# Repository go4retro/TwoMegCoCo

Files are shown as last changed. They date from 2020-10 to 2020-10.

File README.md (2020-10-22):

# TwoMegCoCo - an SRAM-based 2048kB RAM Expansion for the TANDY Color Computer 3
A TTL logic, SRAM-based 2048kB (2MB) memory expansion for the Color Computer 3.  Upper bank registers are write-only, like the older Disto units. All parts are through hole for easy hobbyist assembly.

## Motivation

After acquiring a used Disto 2MB memory expansion, I wondered if a similar 1980's TTL-based solution could have been created using SRAM (ignoring the fact that 2MB of SRAM was extremely expensive at the time compared to DRAM), and I wanted to see if I could design a unit using only off-the-shelf TTL circuitry. (And, since, at time of writing this, the MMU extension PCB is still being debugged, the question is yet unanswered :-)).

Obviously, as with the HalfMegCoco project, there is little economic incentive in this project, as the contemporary commercial solutions offer more functionality at a cheaper price.  But, there's always some value in building a unit oneself, or at least understanding how the MMU process works by inspecting the actual TTL logic.

## Status

Currently, the SRAM board has been confirmed to work with various MMU extension solutions (Boysontech/Cloud9), but I am still designing and debugging the MMU board (would appreciate help, if there is interest).

## License
Copyright (C) 2020  RETRO Innovations

These files are free designs; you can redistribute them and/or modify
them under the terms of the Creative Commons Attribution-ShareAlike 
4.0 International License.

You should have received a copy of the license along with this
work. If not, see <http://creativecommons.org/licenses/by-sa/4.0/>.

These files are distributed in the hope that they will be useful,
but WITHOUT ANY WARRANTY; without even the implied warranty of
MERCHANTABILITY or FITNESS FOR A PARTICULAR PURPOSE.  See the
license for more details.

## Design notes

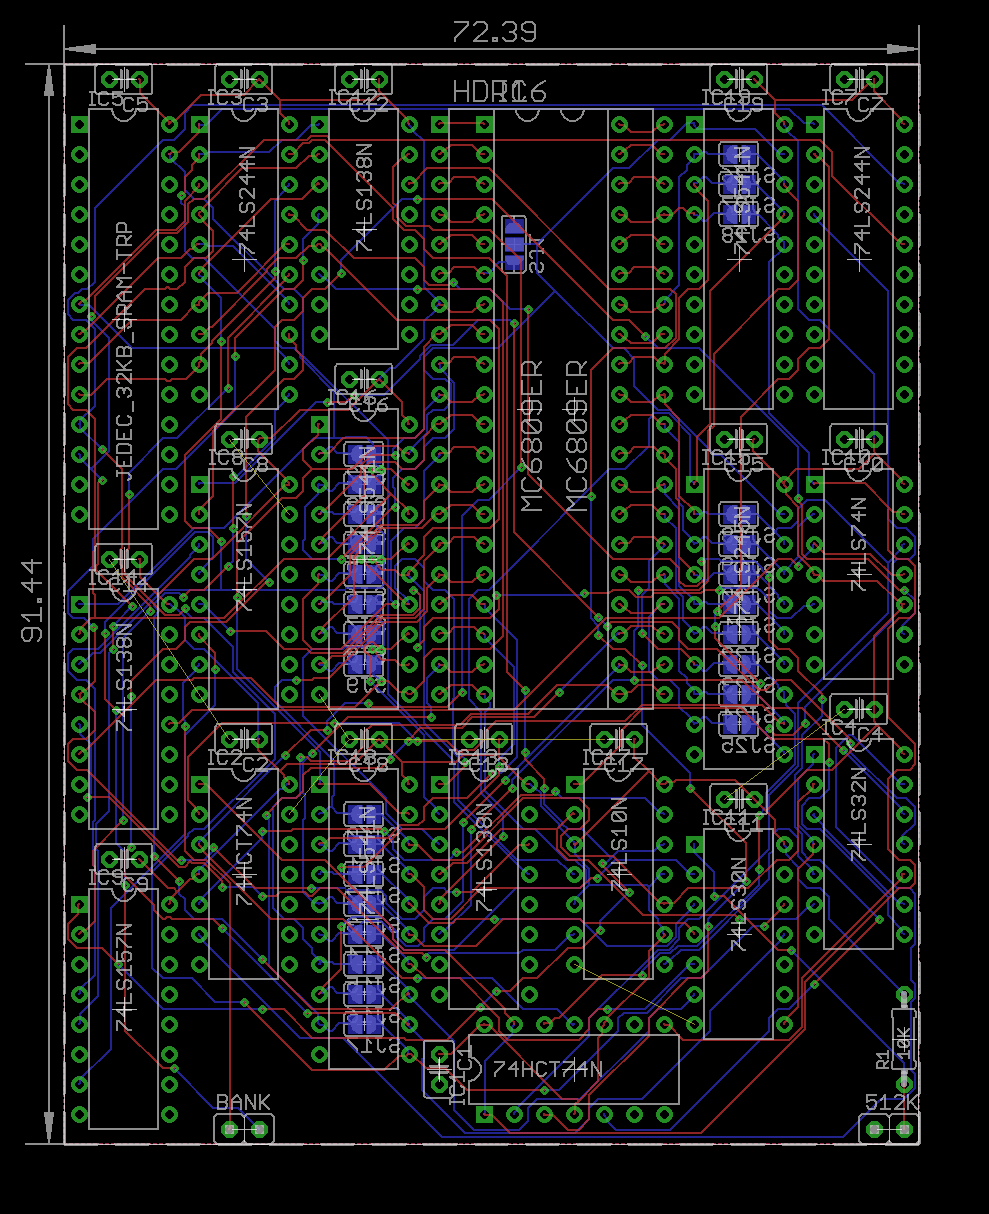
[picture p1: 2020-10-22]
pcb/TwoMegCoCo_MMU_v1.1.png

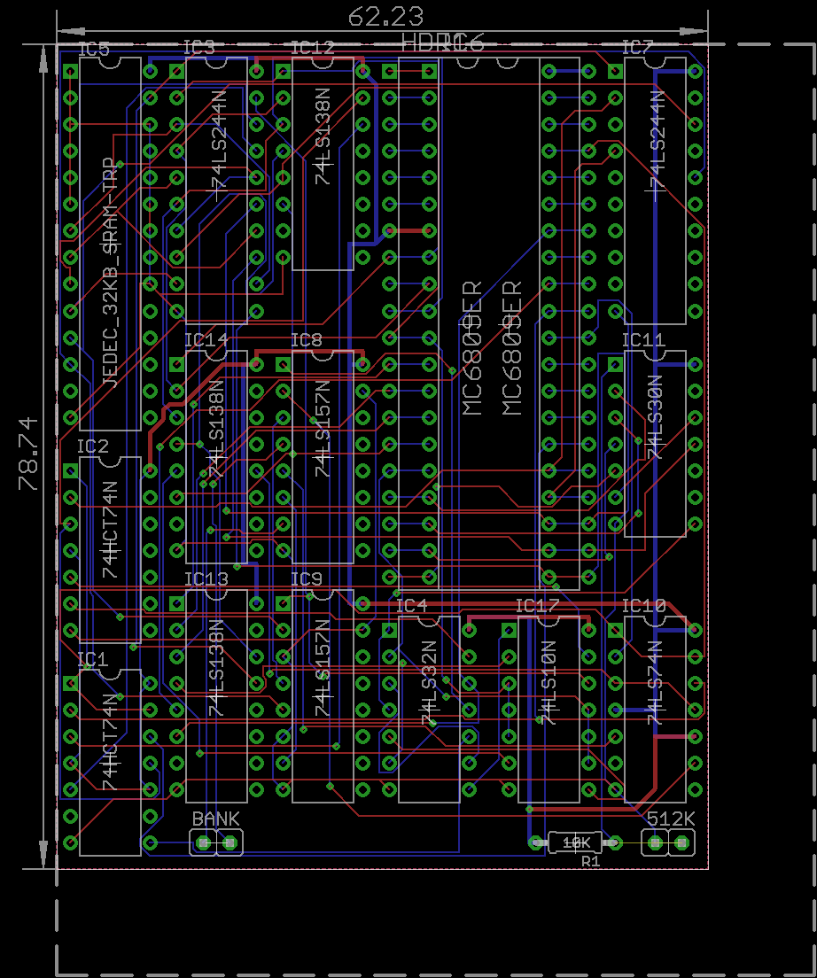
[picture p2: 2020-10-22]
pcb/TwoMegCoCo_MMU_v1.0.png

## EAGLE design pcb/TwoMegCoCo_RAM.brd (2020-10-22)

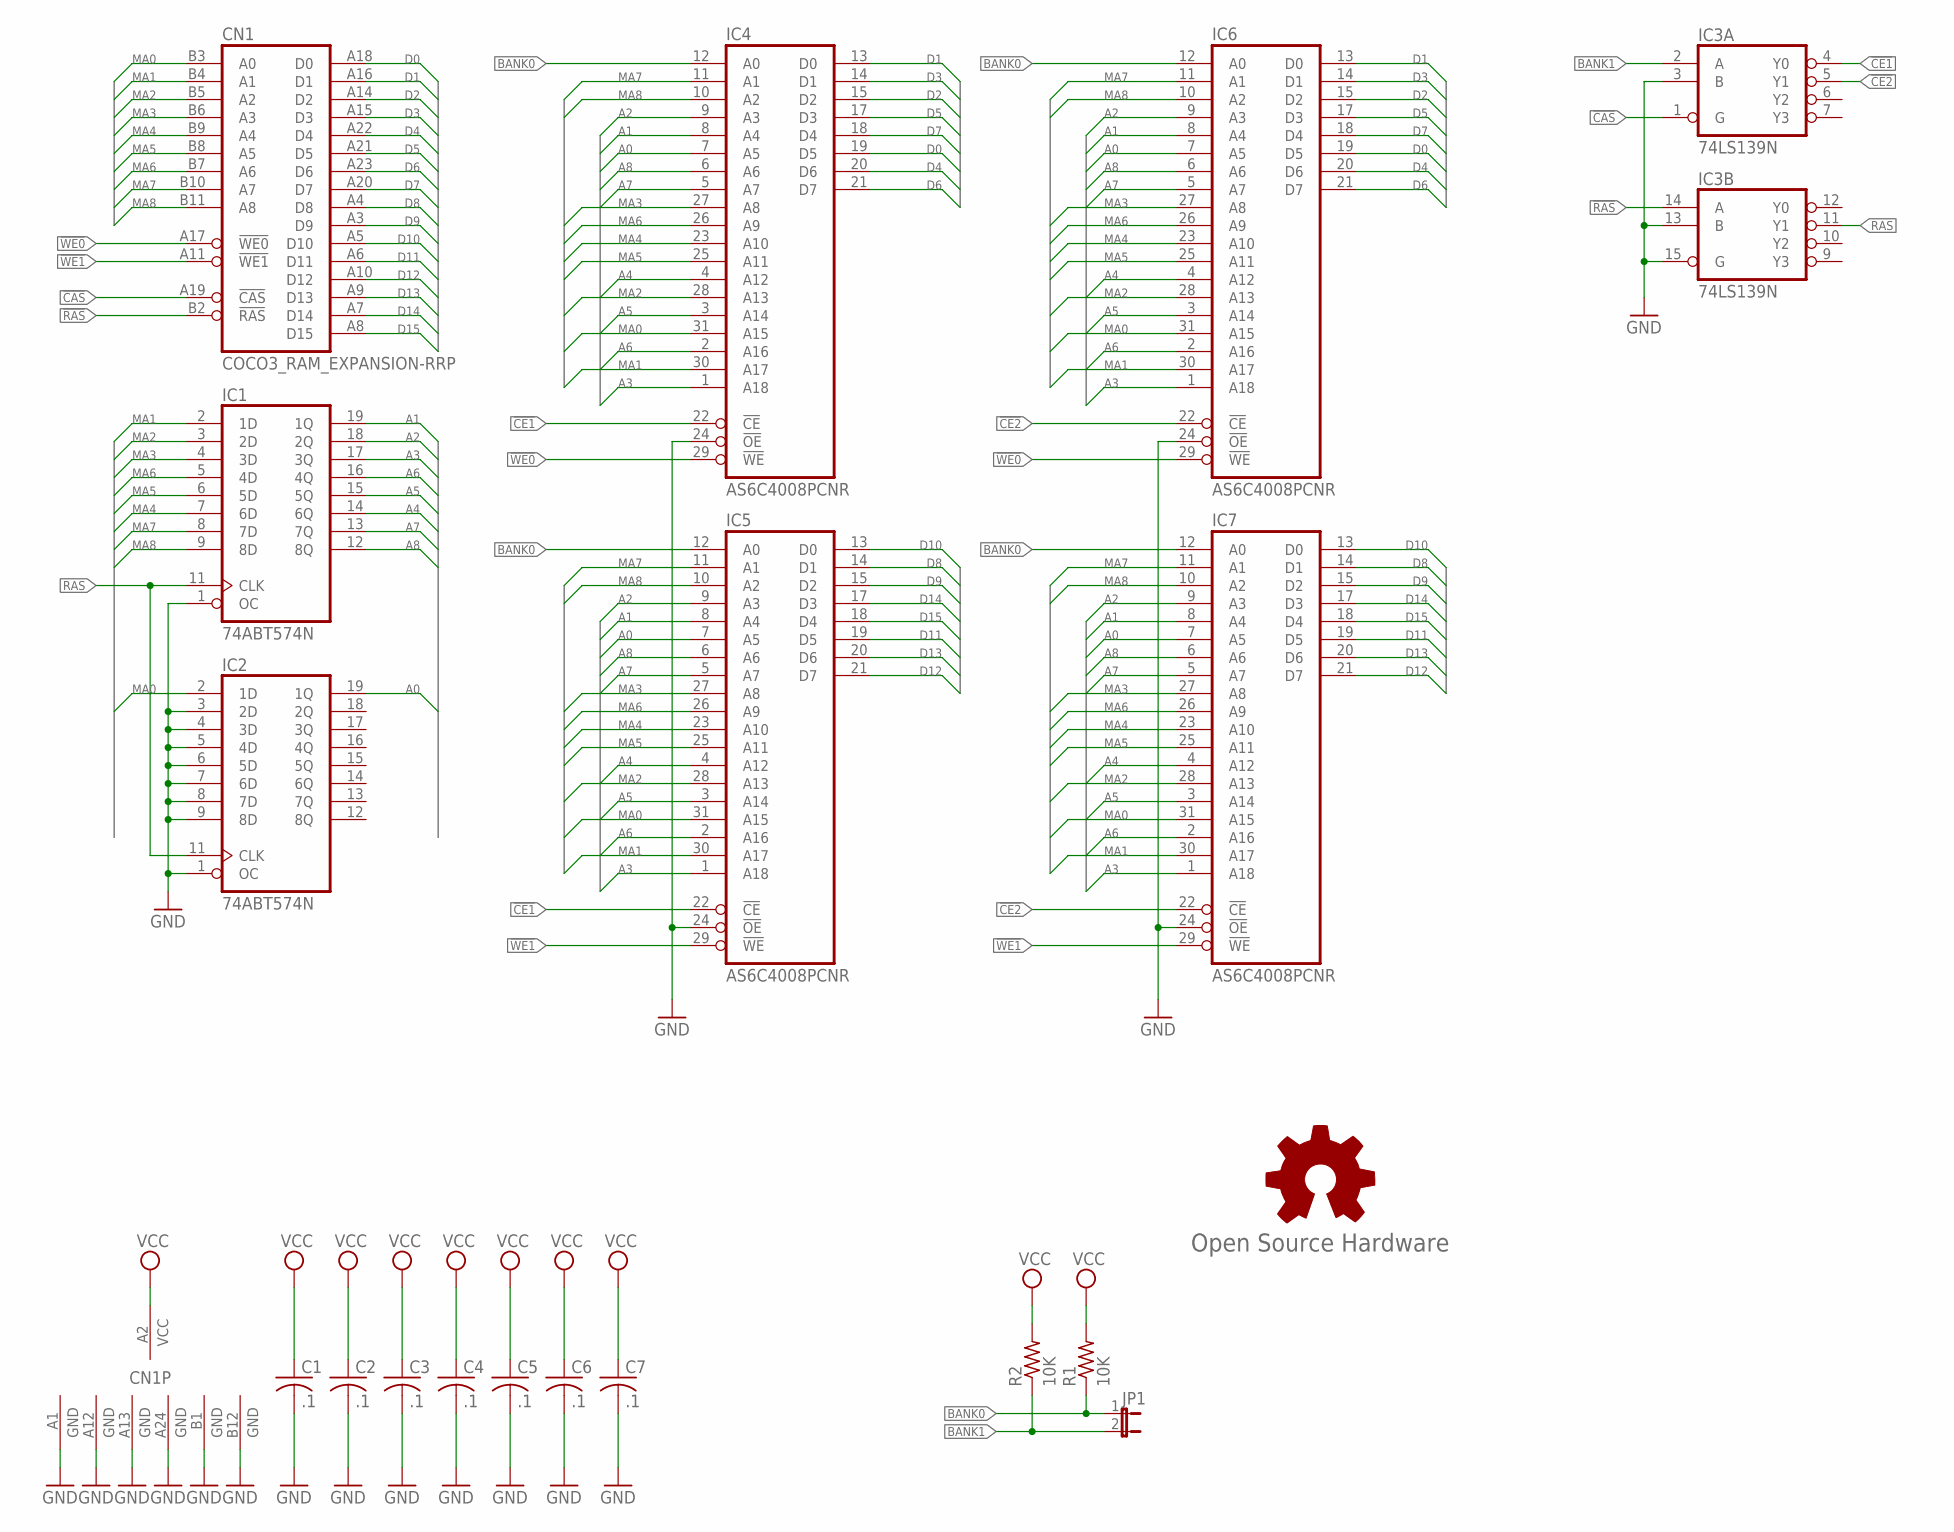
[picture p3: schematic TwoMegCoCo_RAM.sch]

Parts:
C1, C2, C3, C4, C5, C6, C7: .1; C025-025X050
CN1: COCO3_RAM_EXPANSION-RRP; RAM_EXPANSION_REV_RP
GOLD_ORB_SM1: Open Source Hardware; OSHW_8MM
IC1, IC2: 74ABT574N; DIL20-RP
IC3: 74LS139N; DIL16-RP
IC4, IC5, IC6, IC7: AS6C4008PCNR; DIL32-RP
JP1: JP1E; JP1
R1, R2: 10K; 0204/7

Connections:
!CAS: CN1.A19 (!CAS), IC3.1 (G)
!CE1: IC3.4 (Y0), IC4.22 (!CE), IC5.22 (!CE)
!CE2: IC3.5 (Y1), IC6.22 (!CE), IC7.22 (!CE)
!RAS: CN1.B2 (!RAS), IC3.14 (A)
!WE0: CN1.A17 (!WE0), IC4.29 (!WE), IC6.29 (!WE)
!WE1: CN1.A11 (!WE1), IC5.29 (!WE), IC7.29 (!WE)
A0: IC2.19 (1Q), IC4.7 (A5), IC5.7 (A5), IC6.7 (A5), IC7.7 (A5)
A1: IC1.19 (1Q), IC4.8 (A4), IC5.8 (A4), IC6.8 (A4), IC7.8 (A4)
A2: IC1.18 (2Q), IC4.9 (A3), IC5.9 (A3), IC6.9 (A3), IC7.9 (A3)
A3: IC1.17 (3Q), IC4.1 (A18), IC5.1 (A18), IC6.1 (A18), IC7.1 (A18)
A4: IC1.14 (6Q), IC4.4 (A12), IC5.4 (A12), IC6.4 (A12), IC7.4 (A12)
A5: IC1.15 (5Q), IC4.3 (A14), IC5.3 (A14), IC6.3 (A14), IC7.3 (A14)
A6: IC1.16 (4Q), IC4.2 (A16), IC5.2 (A16), IC6.2 (A16), IC7.2 (A16)
A7: IC1.13 (7Q), IC4.5 (A7), IC5.5 (A7), IC6.5 (A7), IC7.5 (A7)
A8: IC1.12 (8Q), IC4.6 (A6), IC5.6 (A6), IC6.6 (A6), IC7.6 (A6)
BANK0: IC4.12 (A0), IC5.12 (A0), IC6.12 (A0), IC7.12 (A0), JP1.1, R1.1
BANK1: IC3.2 (A), JP1.2, R2.1
D0: CN1.A18 (D0), IC4.19 (D5), IC6.19 (D5)
D1: CN1.A16 (D1), IC4.13 (D0), IC6.13 (D0)
D2: CN1.A14 (D2), IC4.15 (D2), IC6.15 (D2)
D3: CN1.A15 (D3), IC4.14 (D1), IC6.14 (D1)
D4: CN1.A22 (D4), IC4.20 (D6), IC6.20 (D6)
D5: CN1.A21 (D5), IC4.17 (D3), IC6.17 (D3)
D6: CN1.A23 (D6), IC4.21 (D7), IC6.21 (D7)
D7: CN1.A20 (D7), IC4.18 (D4), IC6.18 (D4)
D8: CN1.A4 (D8), IC5.14 (D1), IC7.14 (D1)
D9: CN1.A3 (D9), IC5.15 (D2), IC7.15 (D2)
D10: CN1.A5 (D10), IC5.13 (D0), IC7.13 (D0)
D11: CN1.A6 (D11), IC5.19 (D5), IC7.19 (D5)
D12: CN1.A10 (D12), IC5.21 (D7), IC7.21 (D7)
D13: CN1.A9 (D13), IC5.20 (D6), IC7.20 (D6)
D14: CN1.A7 (D14), IC5.17 (D3), IC7.17 (D3)
D15: CN1.A8 (D15), IC5.18 (D4), IC7.18 (D4)
GND: C1.2, C2.2, C3.2, C4.2, C5.2, C6.2, C7.2, CN1.A1 (GND), CN1.A12 (GND), CN1.A13 (GND), CN1.A24 (GND), CN1.B1 (GND), CN1.B12 (GND), IC1.1 (OC), IC1.10 (GND), IC2.1 (OC), IC2.3 (2D), IC2.4 (3D), IC2.5 (4D), IC2.6 (5D), IC2.7 (6D), IC2.8 (7D), IC2.9 (8D), IC2.10 (GND), IC3.3 (B), IC3.8 (GND), IC3.13 (B), IC3.15 (G), IC4.16 (GND), IC4.24 (!OE), IC5.16 (GND), IC5.24 (!OE), IC6.16 (GND), IC6.24 (!OE), IC7.16 (GND), IC7.24 (!OE)
MA0: CN1.B3 (A0), IC2.2 (1D), IC4.31 (A15), IC5.31 (A15), IC6.31 (A15), IC7.31 (A15)
MA1: CN1.B4 (A1), IC1.2 (1D), IC4.30 (A17), IC5.30 (A17), IC6.30 (A17), IC7.30 (A17)
MA2: CN1.B5 (A2), IC1.3 (2D), IC4.28 (A13), IC5.28 (A13), IC6.28 (A13), IC7.28 (A13)
MA3: CN1.B6 (A3), IC1.4 (3D), IC4.27 (A8), IC5.27 (A8), IC6.27 (A8), IC7.27 (A8)
MA4: CN1.B9 (A4), IC1.7 (6D), IC4.23 (A10), IC5.23 (A10), IC6.23 (A10), IC7.23 (A10)
MA5: CN1.B8 (A5), IC1.6 (5D), IC4.25 (A11), IC5.25 (A11), IC6.25 (A11), IC7.25 (A11)
MA6: CN1.B7 (A6), IC1.5 (4D), IC4.26 (A9), IC5.26 (A9), IC6.26 (A9), IC7.26 (A9)
MA7: CN1.B10 (A7), IC1.8 (7D), IC4.11 (A1), IC5.11 (A1), IC6.11 (A1), IC7.11 (A1)
MA8: CN1.B11 (A8), IC1.9 (8D), IC4.10 (A2), IC5.10 (A2), IC6.10 (A2), IC7.10 (A2)
RAS: IC1.11 (CLK), IC2.11 (CLK), IC3.11 (Y1)
VCC: C1.1, C2.1, C3.1, C4.1, C5.1, C6.1, C7.1, CN1.A2 (VCC), IC1.20 (VCC), IC2.20 (VCC), IC3.16 (VCC), IC4.32 (VCC), IC5.32 (VCC), IC6.32 (VCC), IC7.32 (VCC), R1.2, R2.2

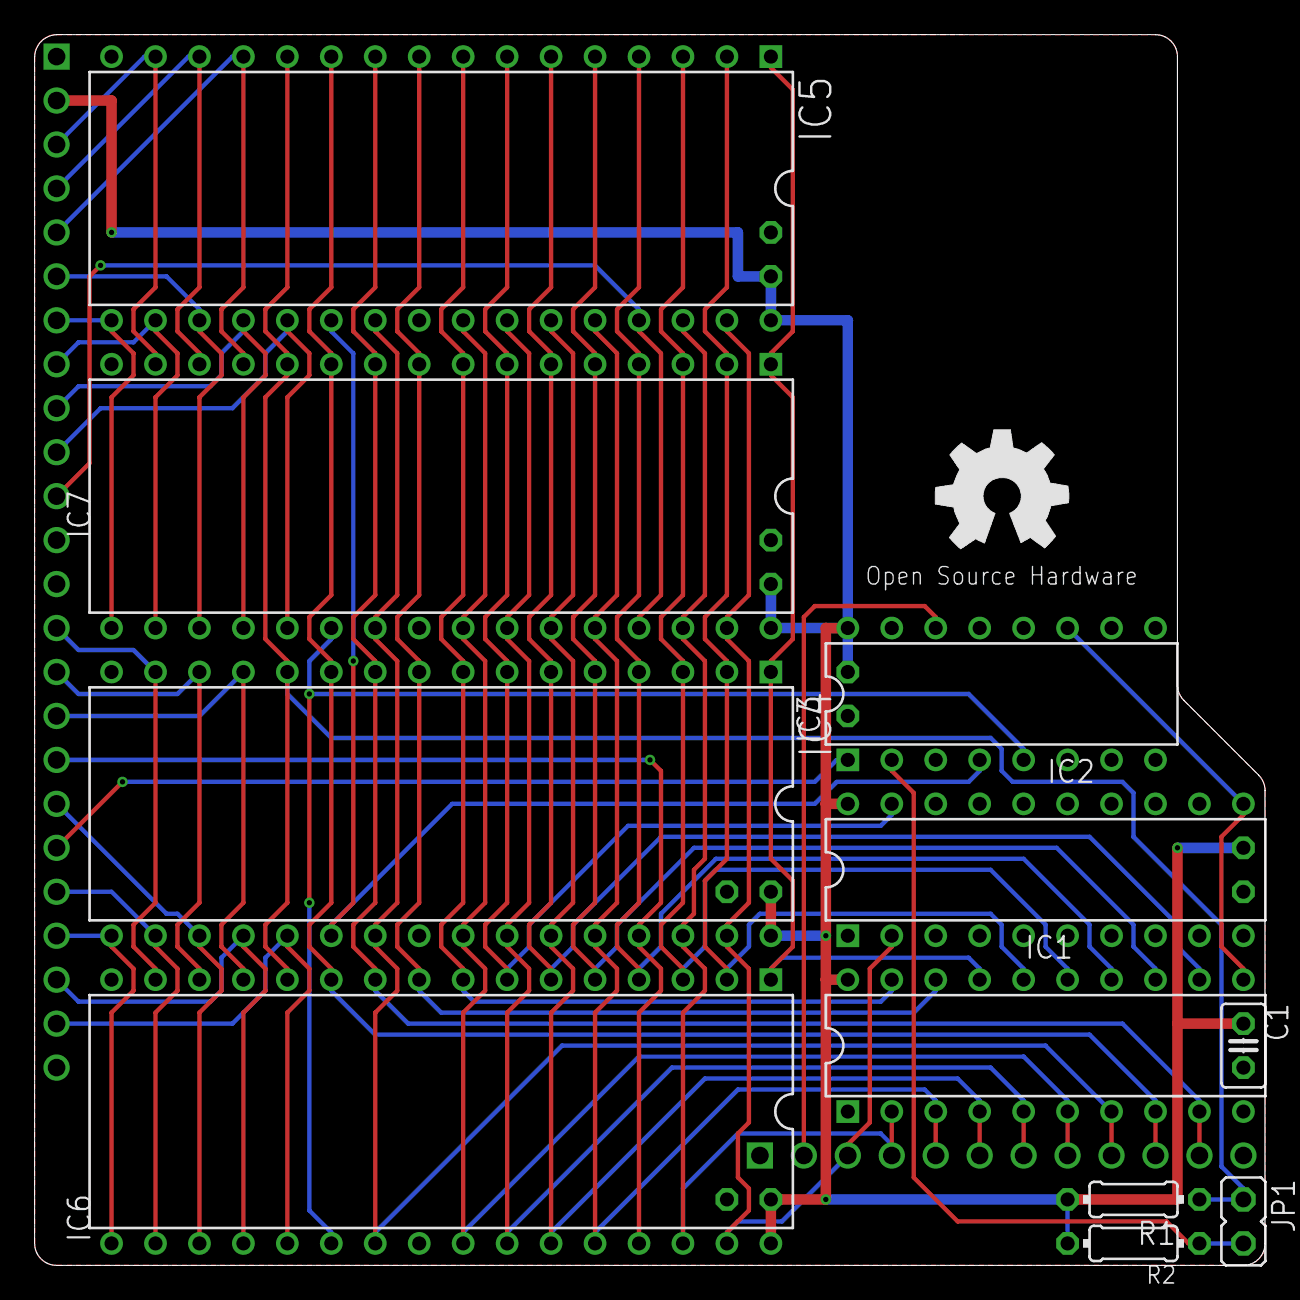
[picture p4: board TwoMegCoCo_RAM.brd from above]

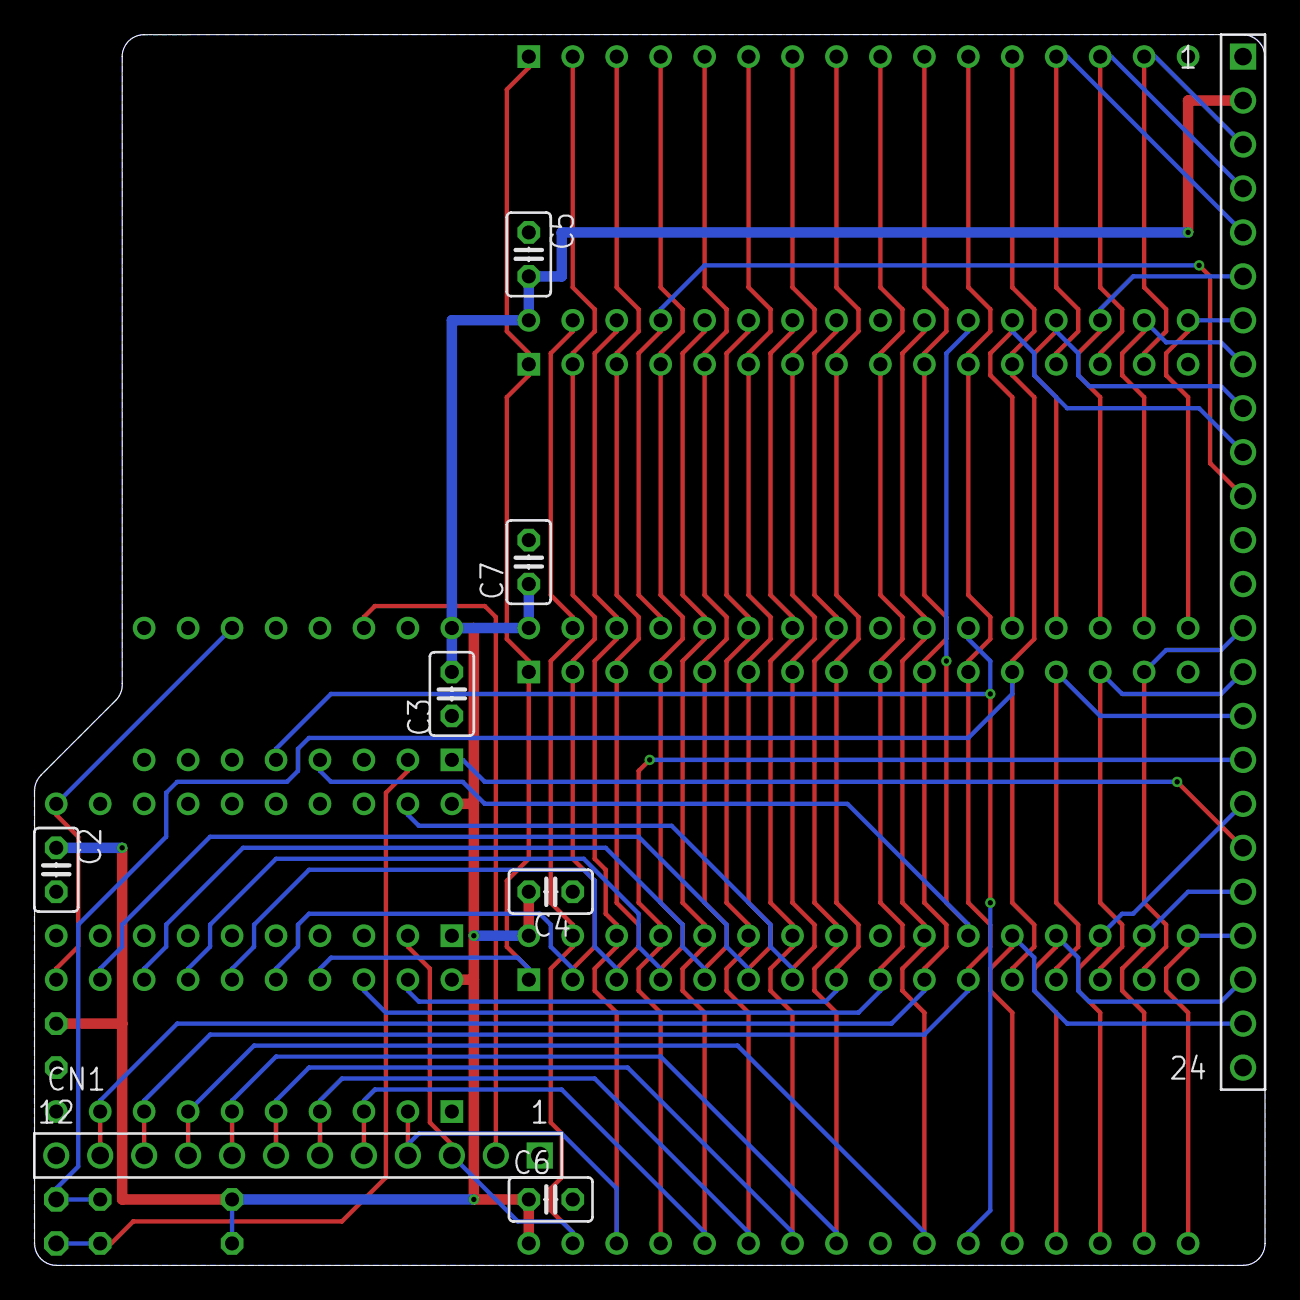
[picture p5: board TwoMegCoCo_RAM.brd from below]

Board: 2 copper layers, 71.1 x 71.1 mm, 19 parts (6 on the bottom side), 45 nets.

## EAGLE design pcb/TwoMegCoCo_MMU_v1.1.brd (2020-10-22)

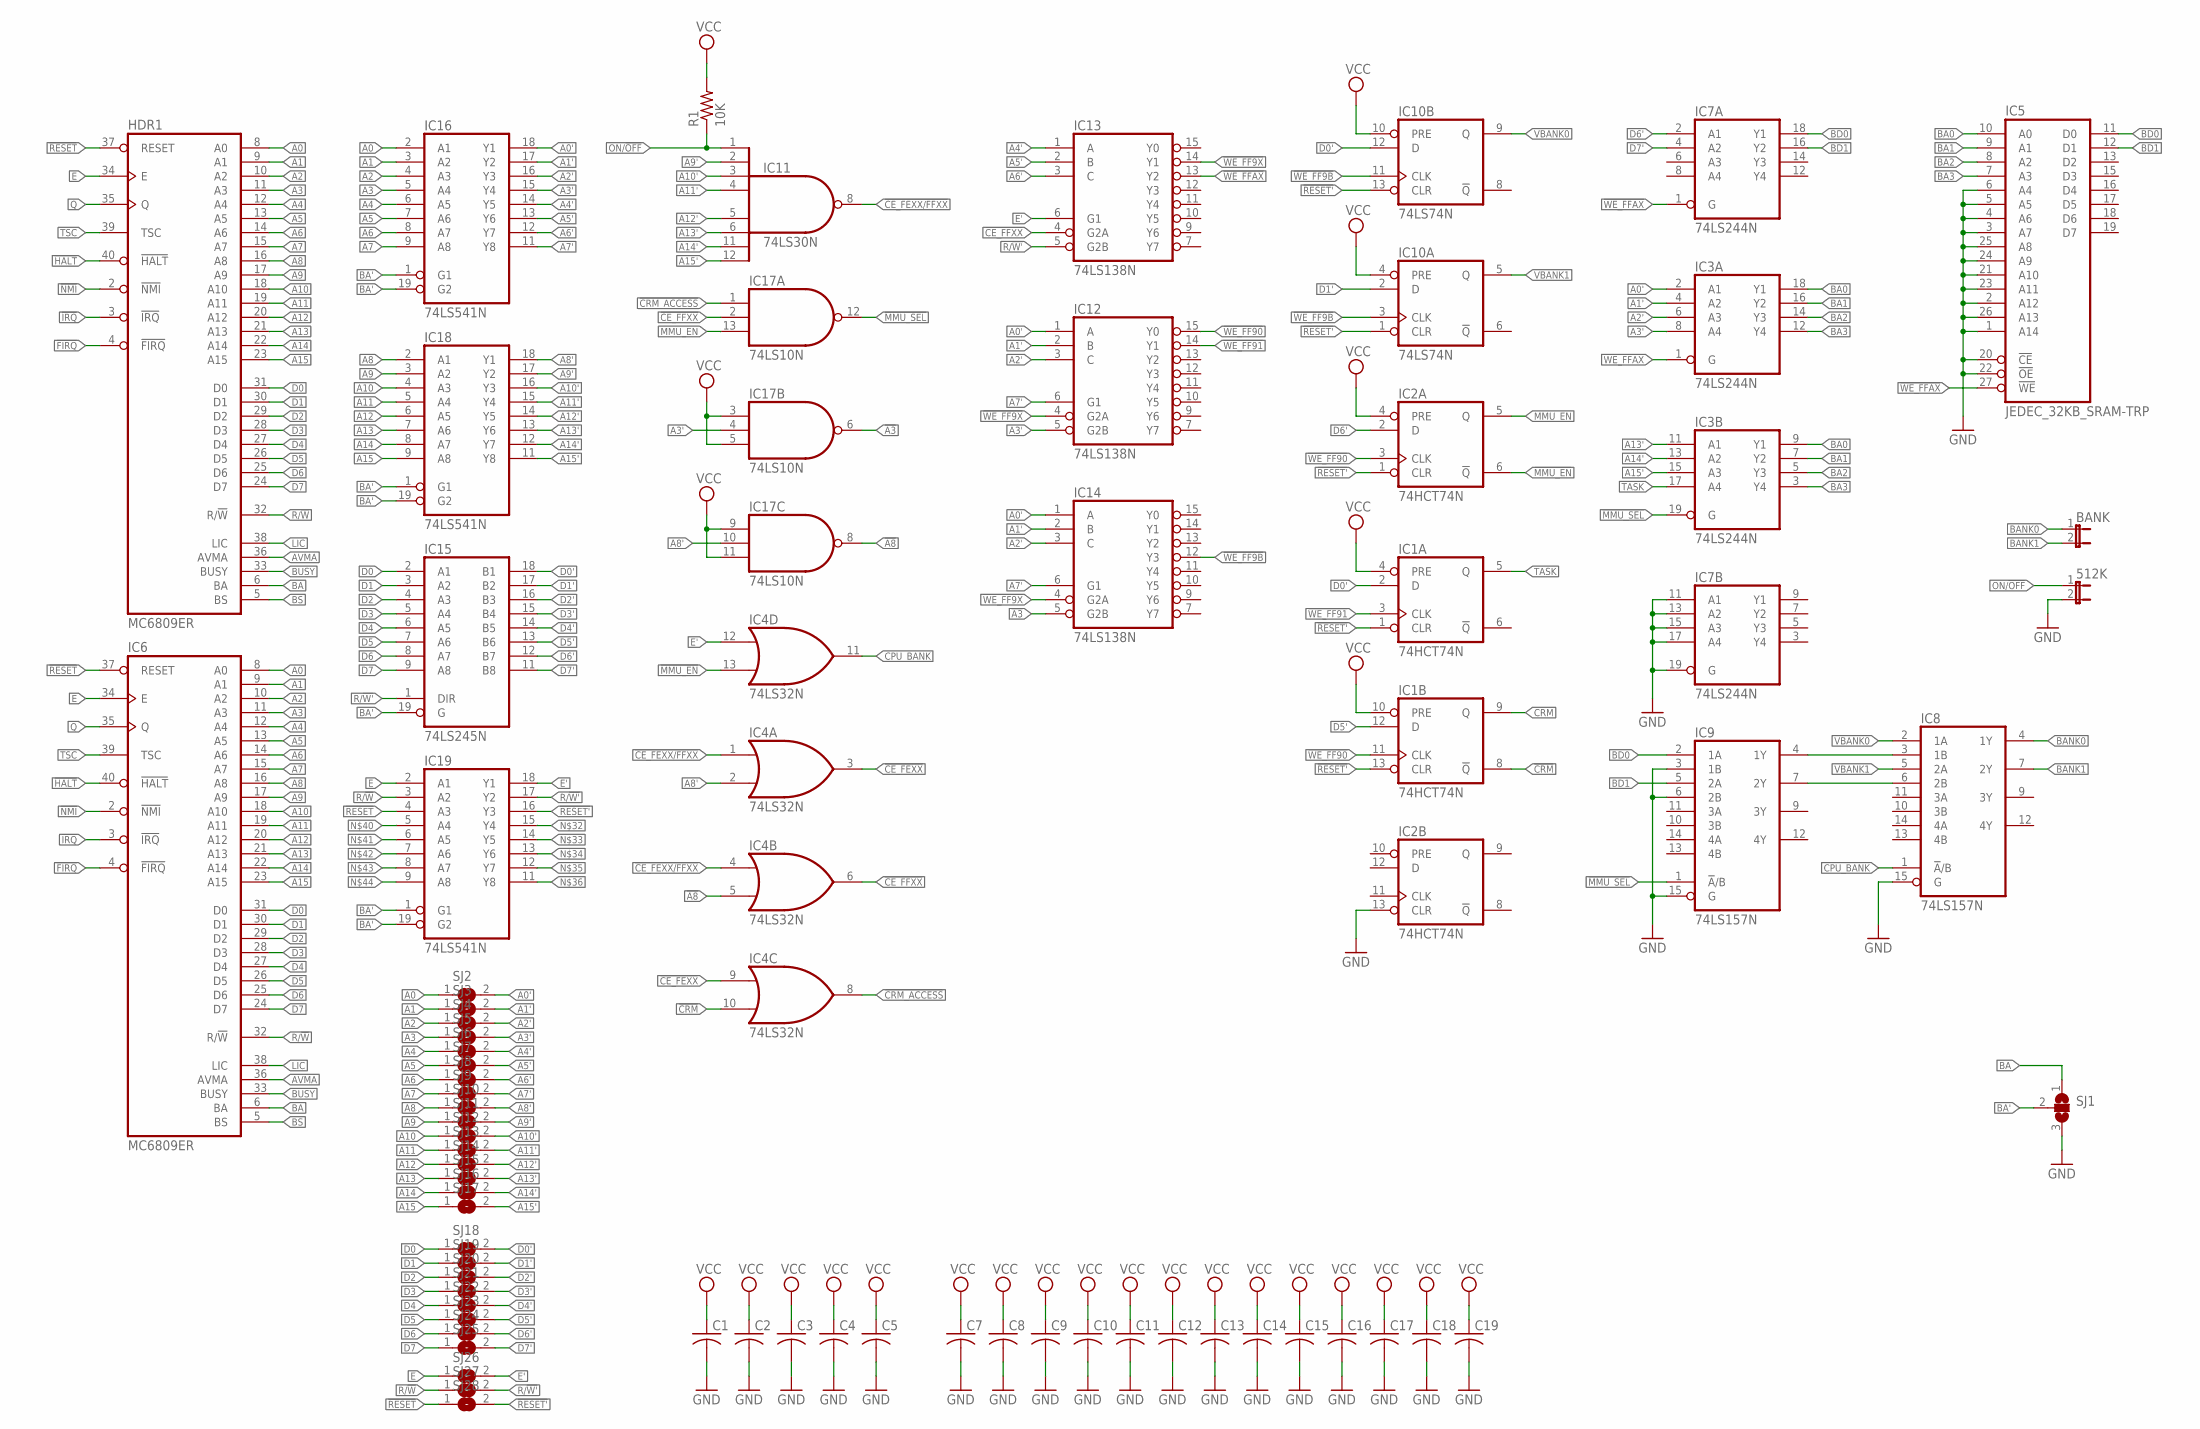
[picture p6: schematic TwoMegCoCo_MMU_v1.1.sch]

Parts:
512K: JP1E; JP1
BANK: JP1E; JP1
C1, C2, C3, C4, C5, C7, C8, C9, C10, C11, C12, C13, C14, C15, C16, C17, C18, C19: C-US025-025X050; C025-025X050
HDR1: MC6809ER; DIL40-ROUNDPAD
IC1, IC2: 74HCT74N; DIL14-RP
IC3, IC7: 74LS244N; DIL20-RP
IC4: 74LS32N; DIL14-RP
IC5: JEDEC_32KB_SRAM-TRP; DIL28-3-RP
IC6: MC6809ER; DIL40-ROUNDPAD
IC8, IC9: 74LS157N; DIL16-RP
IC10: 74LS74N; DIL14-RP
IC11: 74LS30N; DIL14-RP
IC12, IC13, IC14: 74LS138N; DIL16-RP
IC15: 74LS245N; DIL20-RP
IC16, IC18, IC19: 74LS541N; DIL20-RP
IC17: 74LS10N; DIL14-RP
R1: 10K; 0204/7
SJ1: SJ2W; SJ_2
SJ2, SJ3, SJ4, SJ5, SJ6, SJ7, SJ8, SJ9, SJ10, SJ11, SJ12, SJ13, SJ14, SJ15, SJ16, SJ17, SJ18, SJ19, SJ20, SJ21, SJ22, SJ23, SJ24, SJ25, SJ26, SJ27, SJ28: SJ

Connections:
!A3: IC14.5 (G2B), IC17.6 (O)
!A8: IC4.5 (I1), IC17.8 (O)
!CE_FEXX: IC4.3 (O), IC4.9 (I0)
!CE_FEXX/FFXX: IC4.1 (I0), IC4.4 (I0), IC11.8 (O)
!CE_FFXX: IC4.6 (O), IC13.4 (G2A), IC17.2 (I1)
!CRM: IC1.8 (!Q), IC4.10 (I1)
!CRM_ACCESS: IC4.8 (O), IC17.1 (I0)
!FIRQ: HDR1.4 (!FIRQ), IC6.4 (!FIRQ)
!HALT: HDR1.40 (!HALT), IC6.40 (!HALT)
!IRQ: HDR1.3 (!IRQ), IC6.3 (!IRQ)
!MMU_EN: IC2.6 (!Q), IC4.13 (I1)
!MMU_SEL: IC3.19 (G), IC9.1 (!A!/B), IC17.12 (O)
!NMI: HDR1.2 (!NMI), IC6.2 (!NMI)
!RESET: HDR1.37 (RESET), IC6.37 (RESET), IC19.4 (A3), SJ28.1
!RESET': IC1.1 (CLR), IC1.13 (CLR), IC2.1 (CLR), IC10.1 (CLR), IC10.13 (CLR), IC19.16 (Y3), SJ28.2
!WE_FF9B: IC10.3 (CLK), IC10.11 (CLK), IC14.12 (Y3)
!WE_FF9X: IC12.4 (G2A), IC13.14 (Y1), IC14.4 (G2A)
!WE_FF90: IC1.11 (CLK), IC2.3 (CLK), IC12.15 (Y0)
!WE_FF91: IC1.3 (CLK), IC12.14 (Y1)
!WE_FFAX: IC3.1 (G), IC5.27 (!WE), IC7.1 (G), IC13.13 (Y2)
A0: HDR1.8 (A0), IC6.8 (A0), IC16.2 (A1), SJ2.1
A0': IC3.2 (A1), IC12.1 (A), IC14.1 (A), IC16.18 (Y1), SJ2.2
A1: HDR1.9 (A1), IC6.9 (A1), IC16.3 (A2), SJ3.1
A1': IC3.4 (A2), IC12.2 (B), IC14.2 (B), IC16.17 (Y2), SJ3.2
A2: HDR1.10 (A2), IC6.10 (A2), IC16.4 (A3), SJ4.1
A2': IC3.6 (A3), IC12.3 (C), IC14.3 (C), IC16.16 (Y3), SJ4.2
A3: HDR1.11 (A3), IC6.11 (A3), IC16.5 (A4), SJ5.1
A3': IC3.8 (A4), IC12.5 (G2B), IC16.15 (Y4), IC17.4 (I1), SJ5.2
A4: HDR1.12 (A4), IC6.12 (A4), IC16.6 (A5), SJ6.1
A4': IC13.1 (A), IC16.14 (Y5), SJ6.2
A5: HDR1.13 (A5), IC6.13 (A5), IC16.7 (A6), SJ7.1
A5': IC13.2 (B), IC16.13 (Y6), SJ7.2
A6: HDR1.14 (A6), IC6.14 (A6), IC16.8 (A7), SJ8.1
A6': IC13.3 (C), IC16.12 (Y7), SJ8.2
A7: HDR1.15 (A7), IC6.15 (A7), IC16.9 (A8), SJ9.1
A7': IC12.6 (G1), IC14.6 (G1), IC16.11 (Y8), SJ9.2
A8: HDR1.16 (A8), IC6.16 (A8), IC18.2 (A1), SJ10.1
A8': IC4.2 (I1), IC17.10 (I1), IC18.18 (Y1), SJ10.2
A9: HDR1.17 (A9), IC6.17 (A9), IC18.3 (A2), SJ11.1
A9': IC11.2 (I1), IC18.17 (Y2), SJ11.2
A10: HDR1.18 (A10), IC6.18 (A10), IC18.4 (A3), SJ12.1
A10': IC11.3 (I2), IC18.16 (Y3), SJ12.2
A11: HDR1.19 (A11), IC6.19 (A11), IC18.5 (A4), SJ13.1
A11': IC11.4 (I3), IC18.15 (Y4), SJ13.2
A12: HDR1.20 (A12), IC6.20 (A12), IC18.6 (A5), SJ14.1
A12': IC11.5 (I4), IC18.14 (Y5), SJ14.2
A13: HDR1.21 (A13), IC6.21 (A13), IC18.7 (A6), SJ15.1
A13': IC3.11 (A1), IC11.6 (I5), IC18.13 (Y6), SJ15.2
A14: HDR1.22 (A14), IC6.22 (A14), IC18.8 (A7), SJ16.1
A14': IC3.13 (A2), IC11.11 (I6), IC18.12 (Y7), SJ16.2
A15: HDR1.23 (A15), IC6.23 (A15), IC18.9 (A8), SJ17.1
A15': IC3.15 (A3), IC11.12 (I7), IC18.11 (Y8), SJ17.2
AVMA: HDR1.36 (AVMA), IC6.36 (AVMA)
BA: HDR1.6 (BA), IC6.6 (BA), SJ1.1
BA0: IC3.9 (Y1), IC3.18 (Y1), IC5.10 (A0)
BA1: IC3.7 (Y2), IC3.16 (Y2), IC5.9 (A1)
BA2: IC3.5 (Y3), IC3.14 (Y3), IC5.8 (A2)
BA3: IC3.3 (Y4), IC3.12 (Y4), IC5.7 (A3)
BA': IC15.19 (G), IC16.1 (G1), IC16.19 (G2), IC18.1 (G1), IC18.19 (G2), IC19.1 (G1), IC19.19 (G2), SJ1.2
BANK0: BANK.1, IC8.4 (1Y)
BANK1: BANK.2, IC8.7 (2Y)
BD0: IC5.11 (D0), IC7.18 (Y1), IC9.2 (1A)
BD1: IC5.12 (D1), IC7.16 (Y2), IC9.5 (2A)
BS: HDR1.5 (BS), IC6.5 (BS)
BUSY: HDR1.33 (BUSY), IC6.33 (BUSY)
CPU_BANK: IC4.11 (O), IC8.1 (!A!/B)
CRM: IC1.9 (Q)
D0: HDR1.31 (D0), IC6.31 (D0), IC15.2 (A1), SJ18.1
D0': IC1.2 (D), IC10.12 (D), IC15.18 (B1), SJ18.2
D1: HDR1.30 (D1), IC6.30 (D1), IC15.3 (A2), SJ19.1
D1': IC10.2 (D), IC15.17 (B2), SJ19.2
D2: HDR1.29 (D2), IC6.29 (D2), IC15.4 (A3), SJ20.1
D2': IC15.16 (B3), SJ20.2
D3: HDR1.28 (D3), IC6.28 (D3), IC15.5 (A4), SJ21.1
D3': IC15.15 (B4), SJ21.2
D4: HDR1.27 (D4), IC6.27 (D4), IC15.6 (A5), SJ22.1
D4': IC15.14 (B5), SJ22.2
D5: HDR1.26 (D5), IC6.26 (D5), IC15.7 (A6), SJ23.1
D5': IC1.12 (D), IC15.13 (B6), SJ23.2
D6: HDR1.25 (D6), IC6.25 (D6), IC15.8 (A7), SJ24.1
D6': IC2.2 (D), IC7.2 (A1), IC15.12 (B7), SJ24.2
D7: HDR1.24 (D7), IC6.24 (D7), IC15.9 (A8), SJ25.1
D7': IC7.4 (A2), IC15.11 (B8), SJ25.2
E: HDR1.34 (E), IC6.34 (E), IC19.2 (A1), SJ26.1
E': IC4.12 (I0), IC13.6 (G1), IC19.18 (Y1), SJ26.2
GND: 512K.2, C1.2, C2.2, C3.2, C4.2, C5.2, C7.2, C8.2, C9.2, C10.2, C11.2, C12.2, C13.2, C14.2, C15.2, C16.2, C17.2, C18.2, C19.2, IC1.7 (GND), IC2.7 (GND), IC2.13 (CLR), IC3.10 (GND), IC4.7 (GND), IC5.1 (A14), IC5.2 (A12), IC5.3 (A7), IC5.4 (A6), IC5.5 (A5), IC5.6 (A4), IC5.14 (GND), IC5.20 (!CE), IC5.21 (A10), IC5.22 (!OE), IC5.23 (A11), IC5.24 (A9), IC5.25 (A8), IC5.26 (A13), IC7.10 (GND), IC7.11 (A1), IC7.13 (A2), IC7.15 (A3), IC7.17 (A4), IC7.19 (G), IC8.8 (GND), IC8.15 (G), IC9.3 (1B), IC9.6 (2B), IC9.8 (GND), IC9.15 (G), IC10.7 (GND), IC11.7 (GND), IC12.8 (GND), IC13.8 (GND), IC14.8 (GND), IC15.10 (GND), IC16.10 (GND), IC17.7 (GND), IC18.10 (GND), IC19.10 (GND), SJ1.3
LIC: HDR1.38 (LIC), IC6.38 (LIC)
MMU_EN: IC2.5 (Q), IC17.13 (I2)
unnamed: IC8.3 (1B), IC9.4 (1Y)
unnamed: IC8.6 (2B), IC9.7 (2Y)
ON/!OFF: 512K.1, IC11.1 (I0), R1.1
Q: HDR1.35 (Q), IC6.35 (Q)
R/!W: HDR1.32 (R/!W), IC6.32 (R/!W), IC19.3 (A2), SJ27.1
R/!W': IC13.5 (G2B), IC15.1 (DIR), IC19.17 (Y2), SJ27.2
TASK: IC1.5 (Q), IC3.17 (A4)
TSC: HDR1.39 (TSC), IC6.39 (TSC)
VBANK0: IC8.2 (1A), IC10.9 (Q)
VBANK1: IC8.5 (2A), IC10.5 (Q)
VCC: C1.1, C2.1, C3.1, C4.1, C5.1, C7.1, C8.1, C9.1, C10.1, C11.1, C12.1, C13.1, C14.1, C15.1, C16.1, C17.1, C18.1, C19.1, HDR1.7 (VCC), IC1.4 (PRE), IC1.10 (PRE), IC1.14 (VCC), IC2.4 (PRE), IC2.14 (VCC), IC3.20 (VCC), IC4.14 (VCC), IC5.28 (VCC), IC6.7 (VCC), IC7.20 (VCC), IC8.16 (VCC), IC9.16 (VCC), IC10.4 (PRE), IC10.10 (PRE), IC10.14 (VCC), IC11.14 (VCC), IC12.16 (VCC), IC13.16 (VCC), IC14.16 (VCC), IC15.20 (VCC), IC16.20 (VCC), IC17.3 (I0), IC17.5 (I2), IC17.9 (I0), IC17.11 (I2), IC17.14 (VCC), IC18.20 (VCC), IC19.20 (VCC), R1.2
VSS: HDR1.1 (VSS), IC6.1 (VSS)

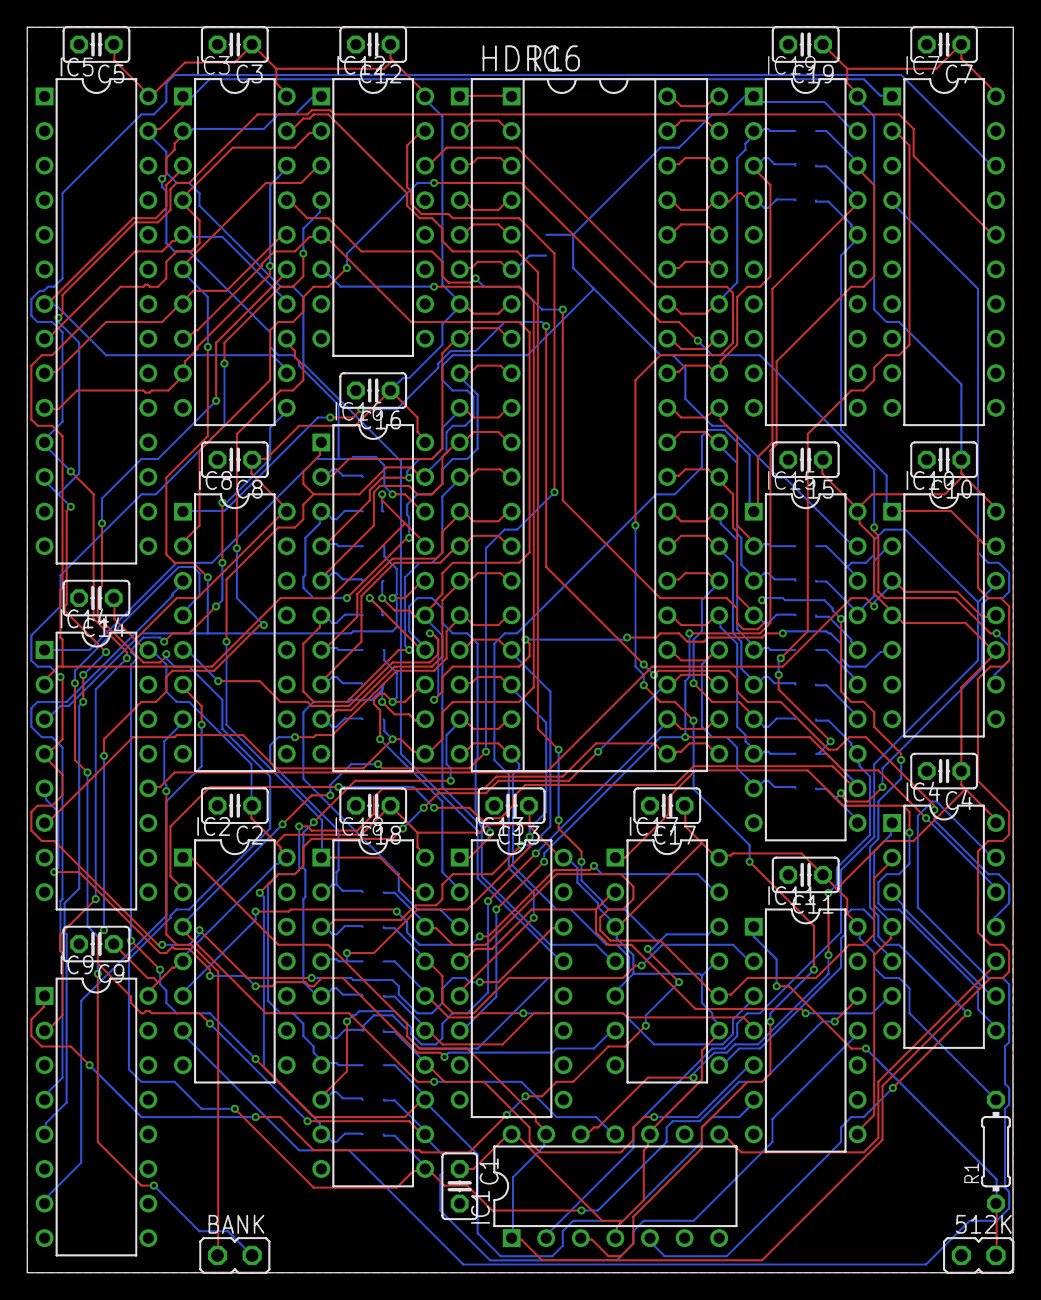
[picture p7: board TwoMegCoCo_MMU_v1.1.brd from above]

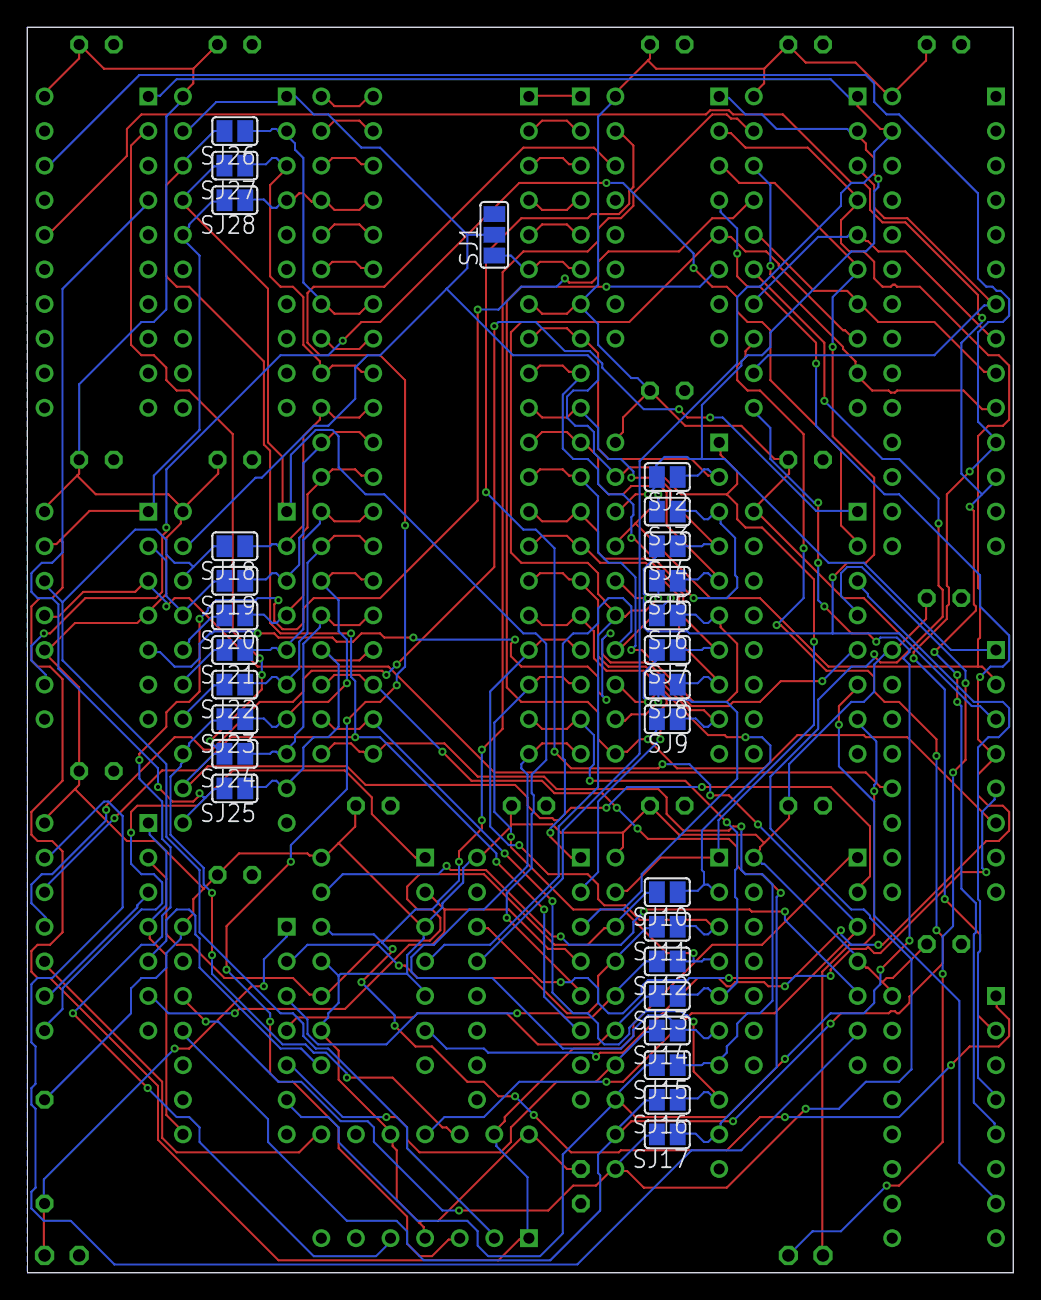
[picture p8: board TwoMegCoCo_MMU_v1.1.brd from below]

Board: 2 copper layers, 72.4 x 91.4 mm, 69 parts (28 on the bottom side), 99 nets.
